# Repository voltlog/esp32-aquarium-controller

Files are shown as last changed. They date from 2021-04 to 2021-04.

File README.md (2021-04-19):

# ESP32 Aquarium/Terarrium Controller

This project started when a friend of mine which has a snake terrarium asked for my help to build a system that is capable of regulating temperature and humidity so the snake can live in optimum conditions. I’m not necessarily a snake lover, I would rather stay away from these kinds of creatures but that doesn’t stop me from helping my friend.

The ESP32 module is the core of this board and it serves as a central processor taking in sensor data and deciding when to switch on/off the 4 relay controlled outputs to adjust the environment inside the aquarium/terrarium.

If you would like to order one of these boards ready assembled, check out my [Tindie store](https://www.tindie.com/products/voltlog/esp32-aquarium-terrarium-controller/).

More info about this project in [Voltlog #361](https://youtu.be/Hlmbx2yu9M0).

Known issues in revA:
- Power brick module footprint is wrong so it needs to be installed on the bottom side of the board. 
- There are no mounting holes.
- Fitting the board inside the intended enclosure required some adjustments on the round cutouts. This is something to consider if you want to use the same enclosure but if you plan to install this in a larger plastic enclosure, it shouldn't be a problem.

## Firmware
Firmware is built as a PlatformIO project on the Arduino platform using publicly available open-source libraries. The HTML page servered by the asyncronous web server needs to be loaded into the ESP32 SPIFFS memory using the standard upload procedure. The code is just a proof of concept and is provided AS IS without warranty of any kind.

## Safety Warning
This control board uses mains voltage so you need to know what you are doing, otherwise, there is a high risk of electrical shock and/or fire. This is a serious topic, if you are not sure what you are doing, ask for help from an electrician. Every connection should be double checked before applying mains power.

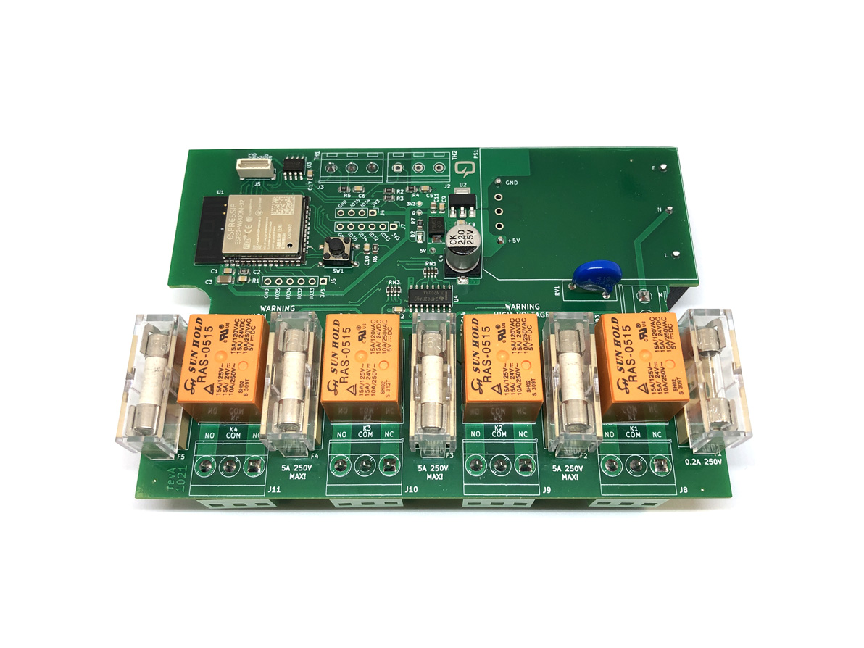
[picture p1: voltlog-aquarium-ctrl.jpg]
Image of the assembled PCB


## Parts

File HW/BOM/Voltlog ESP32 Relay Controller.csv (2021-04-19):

Qty | Reference(s) | Value | Footprint
9 | C1, C2, C5, C6, C8, C9, C10, C12, C17 | 0.1uF | Capacitor_SMD:C_0805_2012Metric
1 | C3 | 22uF | Capacitor_SMD:C_1206_3216Metric
1 | C4 | 220uF | Capacitor_SMD:CP_Elec_8x10.5
6 | C7, C11, C13, C14, C15, C16 | 10uF | Capacitor_SMD:C_0805_2012Metric
1 | D1 | SMBJ6.0A | Diode_SMD:D_SMB
1 | D2 | POWER | LED_SMD:LED_0805_2012Metric
4 | D3, D4, D5, D6 | CH1 | LED_SMD:LED_0805_2012Metric
1 | F1 | 250V 0.5A (slow) | Fuse:Fuseholder_Cylinder-5x20mm_Stelvio-Kontek_PTF78_Horizontal_Open
4 | F2, F3, F4, F5 | Fuse | Fuse:Fuseholder_Cylinder-5x20mm_Stelvio-Kontek_PTF78_Horizontal_Open
1 | J1 | AC_IN | TerminalBlock_RND:TerminalBlock_RND_205-00287_1x02_P5.08mm_Horizontal
1 | J2 | TH2 | TerminalBlock_RND:TerminalBlock_RND_205-00233_1x03_P5.08mm_Horizontal
1 | J3 | TH1 | TerminalBlock_RND:TerminalBlock_RND_205-00233_1x03_P5.08mm_Horizontal
1 | J4 | I2C | Connector_PinHeader_2.54mm:PinHeader_1x04_P2.54mm_Vertical
1 | J5 | VoltLink_target | Voltlog:VoltLink
1 | J6 | ADC | Connector_PinHeader_2.54mm:PinHeader_1x06_P2.54mm_Vertical
1 | J7 | GPIO | Connector_PinHeader_2.54mm:PinHeader_1x06_P2.54mm_Vertical
4 | J8, J9, J10, J11 |  | TerminalBlock_Phoenix:TerminalBlock_Phoenix_MKDS-3-3-5.08_1x03_P5.08mm_Horizontal
4 | K1, K2, K3, K4 | FINDER-36.11 | Relay_THT:Relay_SPDT_Finder_36.11
1 | PS1 | TAS5-5-W | Voltlog:TDPOWER-TAS5
2 | R1, R6 | 10K | Resistor_SMD:R_0805_2012Metric
4 | R2, R3, R4, R5 | 4K7 | Resistor_SMD:R_0805_2012Metric
1 | R7 | 1K | Resistor_SMD:R_0805_2012Metric
1 | RN1 | 270R | Resistor_SMD:R_Array_Convex_4x0603
1 | RN3 | 2K | Resistor_SMD:R_Array_Convex_4x0603
1 | RV1 | 275V | Varistor:RV_Disc_D12mm_W5mm_P7.5mm
1 | SW1 | USER | Button_Switch_SMD:SW_SPST_PTS645
1 | U1 | ESP32-WROOM-32D | RF_Module:ESP32-WROOM-32
1 | U2 | NCP1117-3.3_SOT223 | Package_TO_SOT_SMD:SOT-223-3_TabPin2
1 | U3 | FM24C64C | Package_SO:SOIC-8_3.9x4.9mm_P1.27mm
1 | U4 | ULN2003AD | Package_SO:SO-16_3.9x9.9mm_P1.27mm

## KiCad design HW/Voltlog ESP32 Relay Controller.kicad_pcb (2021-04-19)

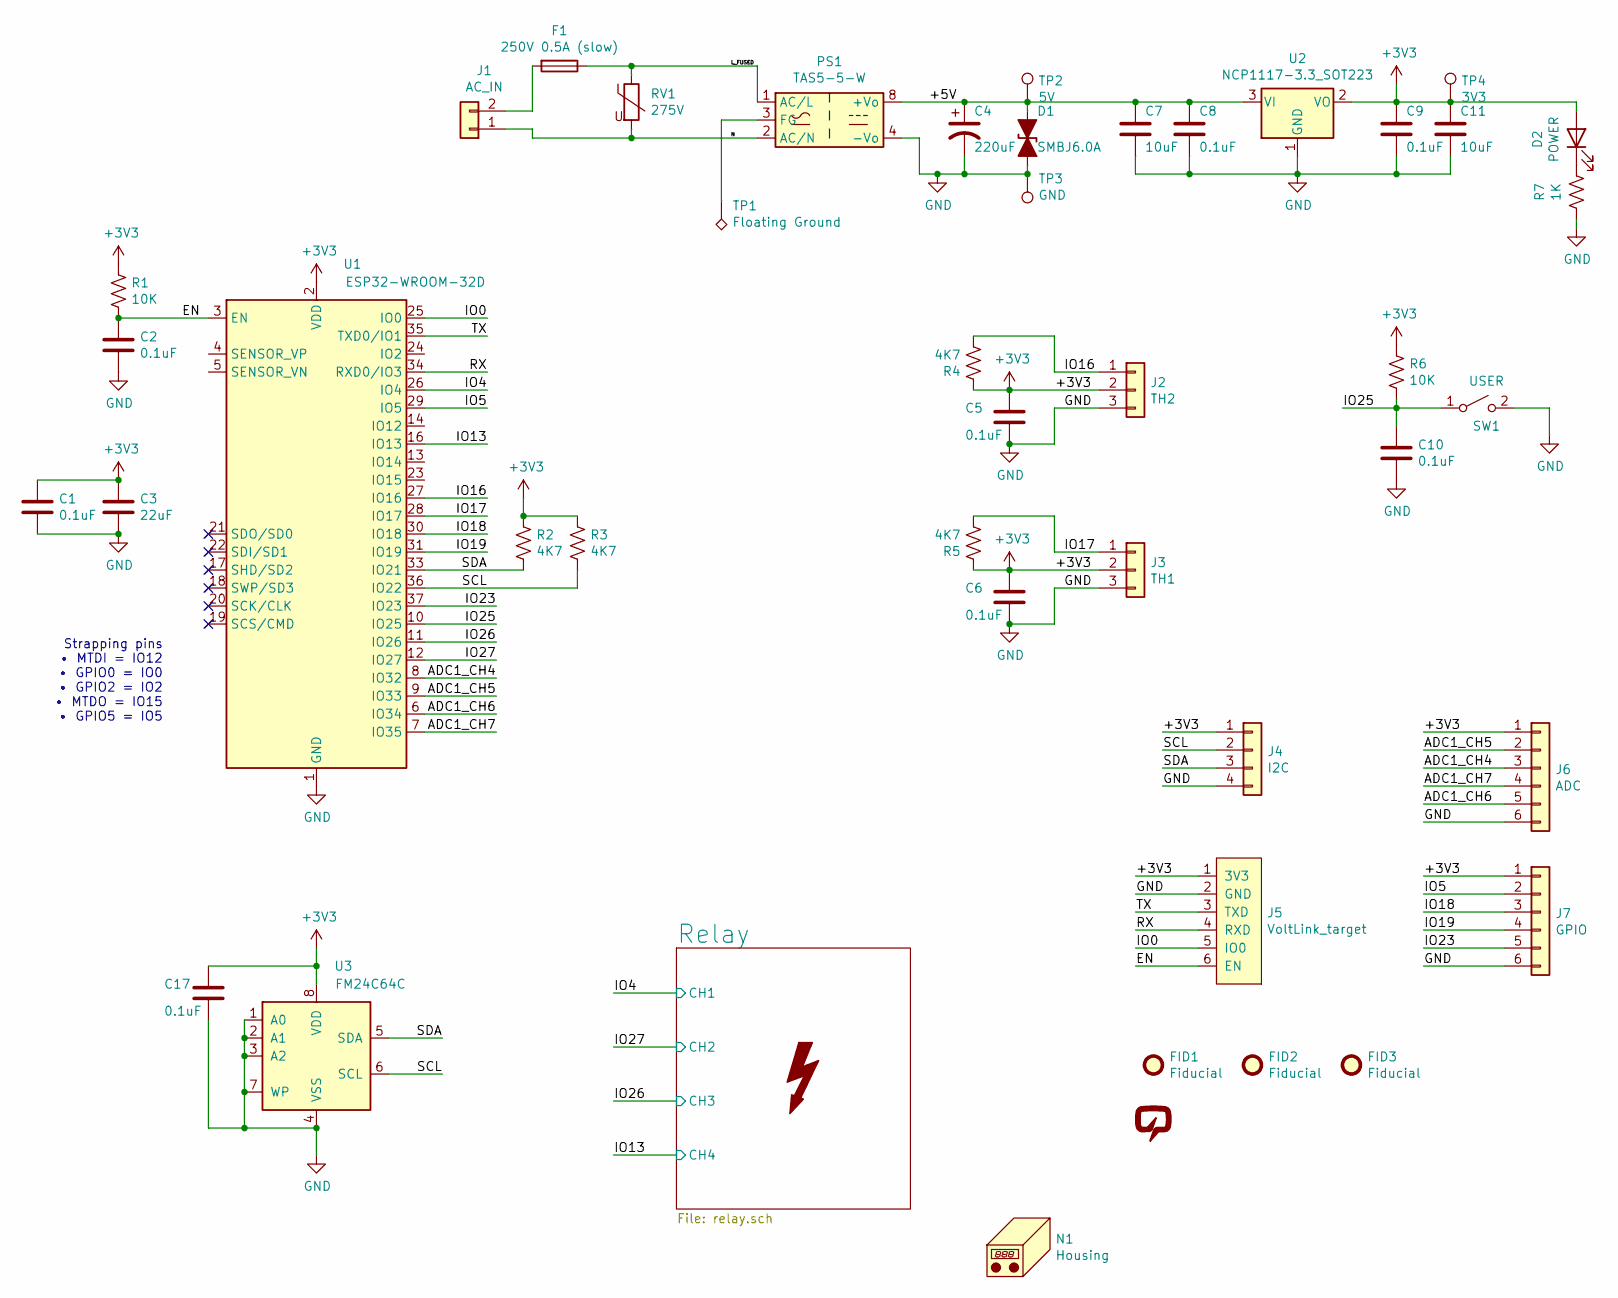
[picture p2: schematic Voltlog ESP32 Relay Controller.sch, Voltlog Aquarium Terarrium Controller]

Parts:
C1, C2, C5, C6, C8, C9, C10, C17: 0.1uF; C_0805_2012Metric
C3: 22uF; C_1206_3216Metric
C4: 220uF; CP_Elec_8x10.5; Voltage 25V
C7, C11: 10uF; C_0805_2012Metric
D1: SMBJ6.0A; D_SMB
D2: POWER; LED_0805_2012Metric
F1: 250V 0.5A (slow); Fuseholder_Cylinder-5x20mm_Stelvio-Kontek_PTF78_Horizontal_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
FID1, FID2, FID3: Fiducial; Fiducial_0.5mm_Mask1mm
J1: AC_IN; TerminalBlock_RND_205-00287_1x02_P5.08mm_Horizontal
J2: TH2; TerminalBlock_RND_205-00233_1x03_P5.08mm_Horizontal
J3: TH1; TerminalBlock_RND_205-00233_1x03_P5.08mm_Horizontal
J4: I2C; PinHeader_1x04_P2.54mm_Vertical
J5: VoltLink_target; VoltLink
J6: ADC; PinHeader_1x06_P2.54mm_Vertical
J7: GPIO; PinHeader_1x06_P2.54mm_Vertical
N1: Housing; Bernic_BE4969842011
PS1: TAS5-5-W; TDPOWER-TAS5
R1, R6: 10K; R_0805_2012Metric
R2, R3, R4, R5: 4K7; R_0805_2012Metric
R7: 1K; R_0805_2012Metric
RV1: 275V; RV_Disc_D12mm_W5mm_P7.5mm
SW1: USER; SW_SPST_PTS645
TP1: Floating Ground; SolderWirePad_1x01_SMD_5x10mm
TP2: 5V; TestPoint_Pad_D1.0mm
TP3: GND; TestPoint_Pad_D1.0mm
TP4: 3V3; TestPoint_Pad_D1.0mm
U1: ESP32-WROOM-32D; ESP32-WROOM-32
U2: NCP1117-3.3_SOT223; SOT-223-3_TabPin2
U3: FM24C64C; SOIC-8_3.9x4.9mm_P1.27mm
V1: VOLTLOG_LOGO; voltlog_mask_5mm

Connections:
+3V3: C1.1, C3.1, C5.1, C6.1, C9.1, C11.1, C17.1, D2.2 (A), J2.2, J3.2, J4.1, J5.1 (3V3), J6.1, J7.1, R1.1, R2.1, R3.1, R4.1, R5.1, R6.1, TP4.1, U1.2 (VDD), U2.2 (VO), U3.8 (VDD)
+5V: C4.1, C7.1, C8.1, D1.1 (A1), PS1.8 (+Vo), TP2.1, U2.3 (VI); also elsewhere on the board
/ADC1_CH4: J6.3, U1.8 (IO32)
/ADC1_CH5: J6.2, U1.9 (IO33)
/ADC1_CH6: J6.5, U1.6 (IO34)
/ADC1_CH7: J6.4, U1.7 (IO35)
/EN: C2.1, J5.6 (EN), R1.2, U1.3 (EN)
/IO0: J5.5 (IO0), U1.25 (IO0)
/IO2: U1.24 (IO2)
/IO4: U1.26 (IO4); also elsewhere on the board
/IO5: J7.2, U1.29 (IO5)
/IO13: U1.16 (IO13); also elsewhere on the board
/IO16: J2.1, R4.2, U1.27 (IO16)
/IO17: J3.1, R5.2, U1.28 (IO17)
/IO18: J7.3, U1.30 (IO18)
/IO19: J7.4, U1.31 (IO19)
/IO23: J7.5, U1.37 (IO23)
/IO25: C10.1, R6.2, SW1.1 (A), U1.10 (IO25)
/IO26: U1.11 (IO26); also elsewhere on the board
/IO27: U1.12 (IO27); also elsewhere on the board
/L_FUSED: F1.1, PS1.1 (AC/L), RV1.1
/N: J1.1, PS1.2 (AC/N), RV1.2
/RX: J5.4 (RXD), U1.34 (RXD0/IO3)
/SCL: J4.2, R3.2, U1.36 (IO22), U3.6 (SCL)
/SDA: J4.3, R2.2, U1.33 (IO21), U3.5 (SDA)
/TX: J5.3 (TXD), U1.35 (TXD0/IO1)
GND: C1.2, C2.2, C3.2, C4.2, C5.2, C6.2, C7.2, C8.2, C9.2, C10.2, C11.2, C17.2, D1.2 (A2), J2.3, J3.3, J4.4, J5.2 (GND), J6.6, J7.6, PS1.4 (-Vo), R7.2, SW1.2 (B), TP3.1, U1.1 (GND), U1.15 (GND), U1.38 (GND), U1.39 (GND), U2.1 (GND), U3.1 (A0), U3.2 (A1), U3.3 (A2), U3.4 (VSS), U3.7 (WP); also elsewhere on the board
unnamed: D2.1 (K), R7.1
unnamed: F1.2, J1.2
unnamed: PS1.3 (FG), TP1.1

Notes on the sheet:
Strapping pins • MTDI = IO12 • GPIO0 = IO0 • GPIO2 = IO2 • MTDO = IO15 • GPIO5 = IO5

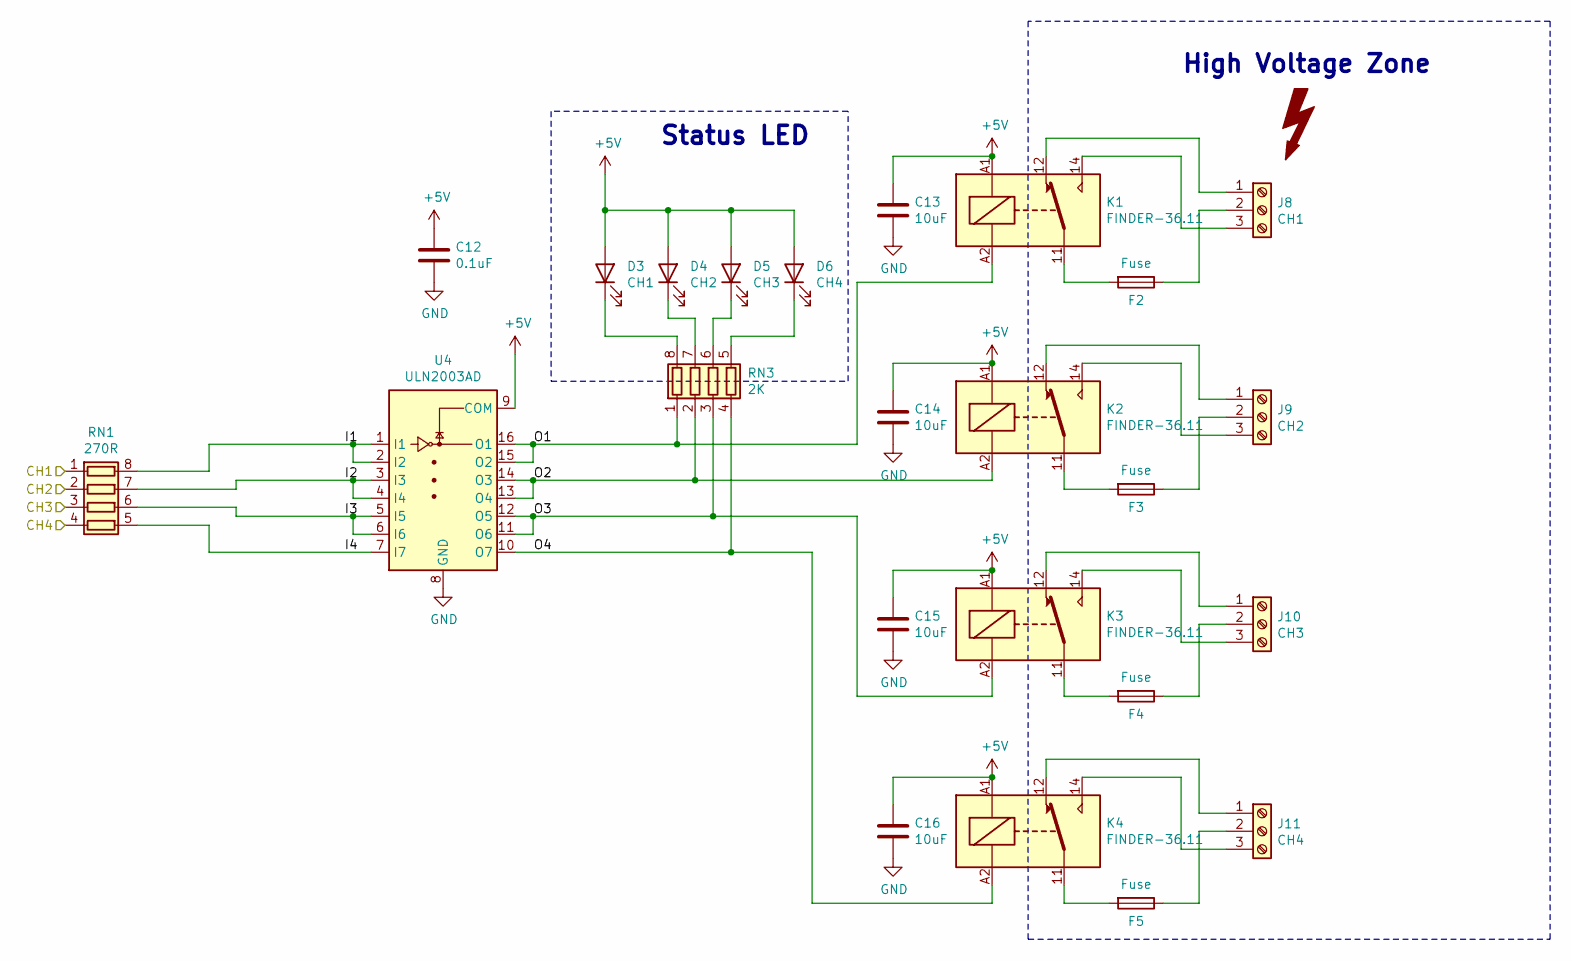
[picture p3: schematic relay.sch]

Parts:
C12: 0.1uF; C_0805_2012Metric
C13, C14, C15, C16: 10uF; C_0805_2012Metric
D3: CH1; LED_0805_2012Metric
D4: CH2; LED_0805_2012Metric
D5: CH3; LED_0805_2012Metric
D6: CH4; LED_0805_2012Metric
F2, F3, F4, F5: Fuse; Fuseholder_Cylinder-5x20mm_Stelvio-Kontek_PTF78_Horizontal_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
J8: CH1; TerminalBlock_Phoenix_MKDS-3-3-5.08_1x03_P5.08mm_Horizontal
J9: CH2; TerminalBlock_Phoenix_MKDS-3-3-5.08_1x03_P5.08mm_Horizontal
J10: CH3; TerminalBlock_Phoenix_MKDS-3-3-5.08_1x03_P5.08mm_Horizontal
J11: CH4; TerminalBlock_Phoenix_MKDS-3-3-5.08_1x03_P5.08mm_Horizontal
K1, K2, K3, K4: FINDER-36.11; Relay_SPDT_Finder_36.11
RN1: 270R; R_Array_Convex_4x0603
RN3: 2K; R_Array_Convex_4x0603
U4: ULN2003AD; SO-16_3.9x9.9mm_P1.27mm

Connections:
+5V: C12.1, C13.2, C14.2, C15.2, C16.2, D3.2 (A), D4.2 (A), D5.2 (A), D6.2 (A), K1.A1, K2.A1, K3.A1, K4.A1, U4.9 (COM); also elsewhere on the board
/IO4: RN1.1 (R1.1); also elsewhere on the board
/IO13: RN1.4 (R4.1); also elsewhere on the board
/IO26: RN1.3 (R3.1); also elsewhere on the board
/IO27: RN1.2 (R2.1); also elsewhere on the board
/Relay/I1: RN1.8 (R1.2), U4.1 (I1), U4.2 (I2)
/Relay/I2: RN1.7 (R2.2), U4.3 (I3), U4.4 (I4)
/Relay/I3: RN1.6 (R3.2), U4.5 (I5), U4.6 (I6)
/Relay/I4: RN1.5 (R4.2), U4.7 (I7)
/Relay/O1: K1.A2, RN3.1 (R1.1), U4.15 (O2), U4.16 (O1)
/Relay/O2: K2.A2, RN3.2 (R2.1), U4.13 (O4), U4.14 (O3)
/Relay/O3: K3.A2, RN3.3 (R3.1), U4.11 (O6), U4.12 (O5)
/Relay/O4: K4.A2, RN3.4 (R4.1), U4.10 (O7)
GND: C12.2, C13.1, C14.1, C15.1, C16.1, U4.8 (GND); also elsewhere on the board
unnamed: D3.1 (K), RN3.8 (R1.2)
unnamed: D4.1 (K), RN3.7 (R2.2)
unnamed: D5.1 (K), RN3.6 (R3.2)
unnamed: D6.1 (K), RN3.5 (R4.2)
unnamed: F2.1, J8.2
unnamed: F2.2, K1.11
unnamed: F3.1, J9.2
unnamed: F3.2, K2.11
unnamed: F4.1, J10.2
unnamed: F4.2, K3.11
unnamed: F5.1, J11.2
unnamed: F5.2, K4.11
unnamed: J8.1, K1.12
unnamed: J8.3, K1.14
unnamed: J9.1, K2.12
unnamed: J9.3, K2.14
unnamed: J10.1, K3.12
unnamed: J10.3, K3.14
unnamed: J11.1, K4.12
unnamed: J11.3, K4.14

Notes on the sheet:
High Voltage Zone
Status LED

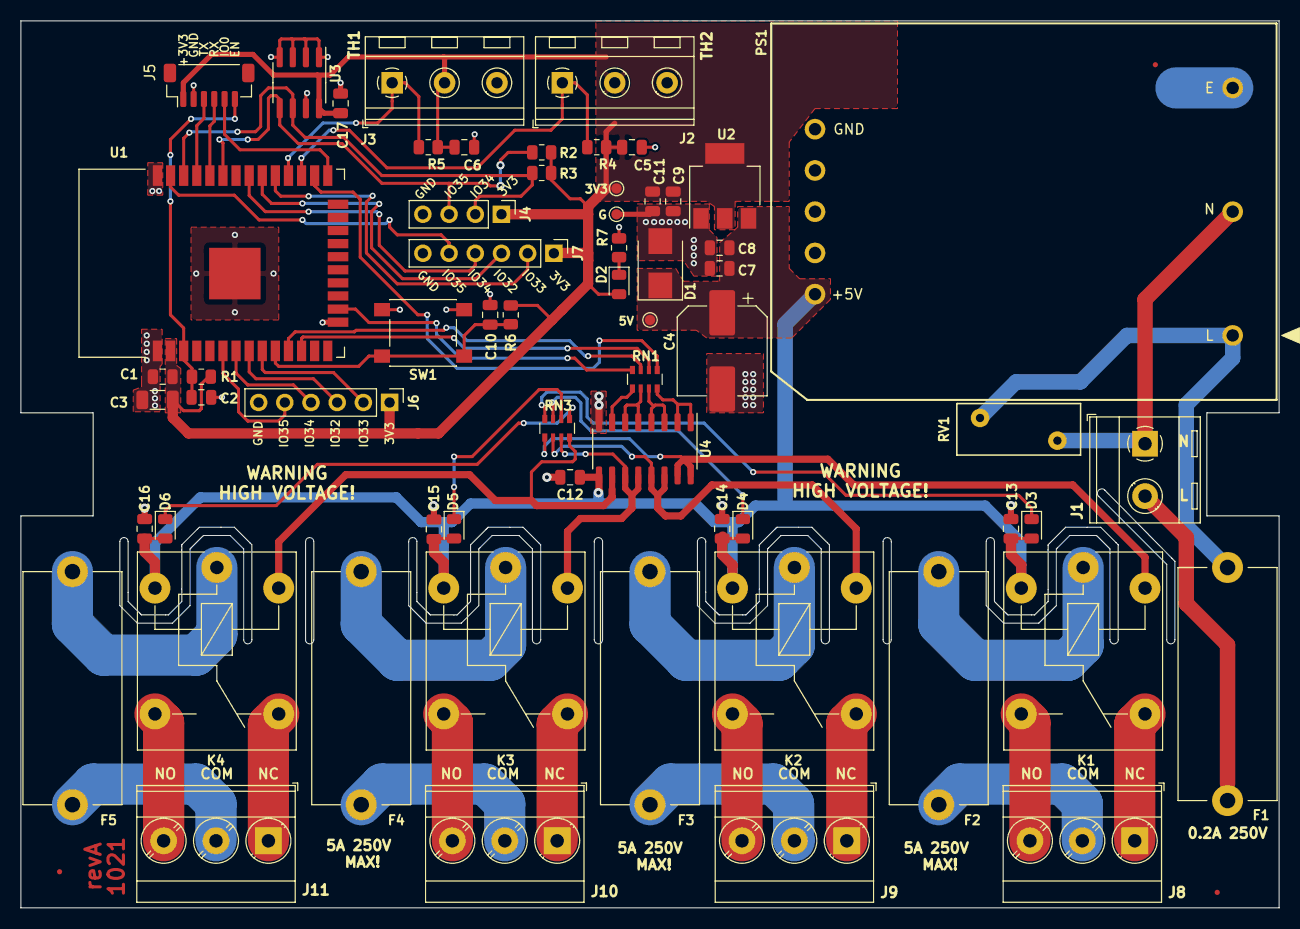
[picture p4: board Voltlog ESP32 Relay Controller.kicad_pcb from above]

Board: 2 copper layers, 122.0 x 86.0 mm, 68 parts (1 on the bottom side), 57 nets.

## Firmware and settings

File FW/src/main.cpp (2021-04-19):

/*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
For more details check out Voltlog #361

This is a work in progress, many of the functions below can be incomplete or may not work
*/
#include <Arduino.h>
#include <WiFi.h>
#include <time.h>
#include <Adafruit_Sensor.h>
#include <DHT.h>
#include <DHT_U.h>
#include <SPIFFS.h>
#include <ESPAsyncWebServer.h>

#define K1pin 4
#define K2pin 27
#define K3pin 26
#define K4pin 13
#define SWITCH 25
#define SENSOR1 17
#define SENSOR2 16
#define DHTTYPE    DHT11     // DHT 11 sensor
#define HEATER K1pin
#define HUMIDIFIER K2pin

const int TEMP1_SET_POINT = 23; // degrees C
int TEMP1 = 0;
const int TEMP1_HYSTERESIS = 1; // 1 degree C of hysteresis
const int HUM1_SET_POINT = 50; // percent
int HUM1 = 0;
const int HUM1_HYSTERESIS = 5; // 5% of hysteresis


String K1status = "OFF";
String K2status = "OFF";
String K3status = "OFF";
String K4status = "OFF";
String Temperature = "-";
String Humidity = "-";
String Mode = "manual";


const char* ssid       = "ssid";
const char* password   = "password";

const char* ntpServer = "pool.ntp.org";
const long  gmtOffset_sec = 7200; //GMT+2 in seconds
const int   daylightOffset_sec = 3600;  //daylight saving in sec
char date_buff[32];

sensor_t sensor1;
DHT_Unified dht(SENSOR1, DHTTYPE);
AsyncWebServer server(80);

void printLocalTime();
char * returnLocalTime();
int getDaylightSavings();
void printSensorDiagnostic();
void printSensorData();
void getSensorData();
String processor(const String& var);
void updateHumidifier();
void updateHeater();
void configWebServer();


void setup() {
  // Init UART interface
  Serial.begin(115200);

  // Init SPIFFS
  if(!SPIFFS.begin()){
  Serial.println("An Error has occurred while mounting SPIFFS");
  return;
  }

  // Init IO pins
  pinMode(K1pin, OUTPUT);
  pinMode(K2pin, OUTPUT);
  pinMode(K3pin, OUTPUT);
  pinMode(K4pin, OUTPUT);
  pinMode(SWITCH, INPUT);

  // Init & connect to WiFi
  Serial.printf("Connecting to %s ", ssid);
  WiFi.begin(ssid, password);
  while (WiFi.status() != WL_CONNECTED) {
      delay(500);
      Serial.print(".");
  }
  Serial.println(" CONNECTED");
  Serial.print("Got IP: ");  Serial.println(WiFi.localIP());

  //config webserver
  configWebServer();

  //config time
  Serial.println("Configuring NTP service and fetching current time.");
  configTime(gmtOffset_sec, 0, ntpServer);  //start with DST 0 to be able to config and get initial time
  printLocalTime();
  Serial.println("Adjusting for DST.");
  configTime(gmtOffset_sec, getDaylightSavings(), ntpServer);
  printLocalTime();

  //Initialize DHT sensor
  dht.begin();
  //printSensorDiagnostic();


  //Print stored config variables
  Serial.println("Retrieving stored settings from memory...");
  Serial.print  (F("TEMP1_SET_POINT: ")); Serial.println(TEMP1_SET_POINT);
  Serial.print  (F("TEMP1_HYSTERESIS: ")); Serial.println(TEMP1_HYSTERESIS);
  Serial.print  (F("HUM1_SET_POINT: ")); Serial.println(HUM1_SET_POINT);
  Serial.print  (F("HUM1_HYSTERESIS: ")); Serial.println(HUM1_HYSTERESIS);


  delay(1000);
  Serial.println("System ready.");
}

void loop() {
  
  //printLocalTime();
  getSensorData();
  printSensorData();
  updateHumidifier();
  updateHeater();

  delay(1000);

  //TODO Add safety checks for temp / hum values
  //TODO add watchdog that resets system in case of lockup


  // RUN THIS TO UPDATE TIME FRON NTP SERVER
  //  configTime(gmtOffset_sec, getDaylightSavings(), ntpServer);

}

String processor(const String& var){
  if (var == "TIME"){
    return returnLocalTime();
  }
  else if (var == "TEMP"){
    return Temperature;
  }
  else if (var == "HUMIDITY"){
    return Humidity;
  }
  else if (var == "OUTPUT1_STATUS"){
    return K1status;
  }
  else if (var == "OUTPUT2_STATUS"){
    return K2status;
  }
  else if (var == "OUTPUT3_STATUS"){
    return K3status;
  }
  else if (var == "OUTPUT4_STATUS"){
    return K4status;
  }
  return String();
}

void getSensorData()
{
    // Get temperature event and print its value.
  sensors_event_t event;
  dht.temperature().getEvent(&event);
  if (isnan(event.temperature)) {
   //Serial.println(F("Error reading temperature!"));
  }
  else {
    //Serial.print(F("Temperature: "));
    //Serial.print(event.temperature);
    //Serial.println(F("°C"));
    TEMP1 = event.temperature;
    Temperature = event.temperature;
  }
  // Get humidity event and print its value.
  dht.humidity().getEvent(&event);
  if (isnan(event.relative_humidity)) {
    //Serial.println(F("Error reading humidity!"));
  }
  else {
    //Serial.print(F("Humidity: "));
    //Serial.print(event.relative_humidity);
    //Serial.println(F("%"));
    HUM1 = event.relative_humidity;
    Humidity = event.relative_humidity;
  }
}

//config webserver
void configWebServer() {
  server.on("/", HTTP_GET, [](AsyncWebServerRequest *request){request->send(SPIFFS, "/index.html", String(), false, processor);});
  server.on("/bootstrap.min.css", HTTP_GET, [](AsyncWebServerRequest *request){request->send(SPIFFS, "/bootstrap.min.css", "text/css");});
  server.on("/output1_on", HTTP_GET, [](AsyncWebServerRequest *request){digitalWrite(K1pin, HIGH);K1status="ON";request->send(SPIFFS, "/index.html", String(), false, processor);});
  server.on("/output1_off", HTTP_GET, [](AsyncWebServerRequest *request){digitalWrite(K1pin, LOW);K1status="OFF";request->send(SPIFFS, "/index.html", String(), false, processor);});
  server.on("/output2_on", HTTP_GET, [](AsyncWebServerRequest *request){digitalWrite(K2pin, HIGH);K2status="ON";request->send(SPIFFS, "/index.html", String(), false, processor);});
  server.on("/output2_off", HTTP_GET, [](AsyncWebServerRequest *request){digitalWrite(K2pin, LOW);K2status="OFF";request->send(SPIFFS, "/index.html", String(), false, processor);});
  server.on("/output3_on", HTTP_GET, [](AsyncWebServerRequest *request){digitalWrite(K3pin, HIGH);K3status="ON";request->send(SPIFFS, "/index.html", String(), false, processor);});
  server.on("/output3_off", HTTP_GET, [](AsyncWebServerRequest *request){digitalWrite(K3pin, LOW);K3status="OFF";request->send(SPIFFS, "/index.html", String(), false, processor);});
  server.on("/output4_on", HTTP_GET, [](AsyncWebServerRequest *request){digitalWrite(K4pin, HIGH);K4status="ON";request->send(SPIFFS, "/index.html", String(), false, processor);});
  server.on("/output4_off", HTTP_GET, [](AsyncWebServerRequest *request){digitalWrite(K4pin, LOW);K4status="OFF";request->send(SPIFFS, "/index.html", String(), false, processor);});

  server.on("/temperature", HTTP_GET, [](AsyncWebServerRequest *request){request->send_P(200, "text/plain", Temperature.c_str());});
  server.on("/humidity", HTTP_GET, [](AsyncWebServerRequest *request){request->send_P(200, "text/plain", Humidity.c_str());});
  server.on("/time", HTTP_GET, [](AsyncWebServerRequest *request){request->send_P(200, "text/plain", returnLocalTime());});
  server.on("/auto", HTTP_GET, [](AsyncWebServerRequest *request){Mode="auto";request->send_P(200, "text/plain", Mode.c_str());});
  server.on("/manual", HTTP_GET, [](AsyncWebServerRequest *request){Mode="manual";request->send_P(200, "text/plain", Mode.c_str());});
  server.on("/get_mode", HTTP_GET, [](AsyncWebServerRequest *request){request->send_P(200, "application/json", Mode.c_str());});
  
  server.begin();
}

//Function that controls the heater output
void updateHeater() {                         
  static double lastTemp = 0;
  if (lastTemp != TEMP1) {
    digitalWrite(HEATER, TEMP1 <= TEMP1_SET_POINT - TEMP1_HYSTERESIS ? HIGH : LOW);
    lastTemp = TEMP1;
  }
}

void updateHumidifier() {                         
  static double lastHum = 0;
  if (lastHum != HUM1) {
    digitalWrite(HUMIDIFIER, HUM1 <= HUM1_SET_POINT - HUM1_HYSTERESIS ? HIGH : LOW);
    lastHum = HUM1;
  }
}

void printLocalTime()
{
  struct tm timeinfo;
  if(!getLocalTime(&timeinfo)){
    Serial.println("Failed to obtain time");
    return;
  }
  Serial.println(&timeinfo, "%A, %B %d %Y %H:%M:%S");
}

char * returnLocalTime()
{
  struct tm timeinfo;
  
  if(!getLocalTime(&timeinfo)){
    Serial.println("Failed to obtain time");
  } 
  strftime(date_buff, 32, "%A, %B %d %Y %H:%M:%S", &timeinfo);
  return date_buff;

}


int getDaylightSavings()
{
  struct tm timeinfo;
  int daylightOffset;
  
  if(!getLocalTime(&timeinfo)){
    Serial.println("Failed to obtain time");
  } 
  daylightOffset =  daylightOffset_sec * timeinfo.tm_isdst;
  return daylightOffset;
}

void printSensorDiagnostic()
{
  dht.temperature().getSensor(&sensor1);
  Serial.println(F("------------------------------------"));
  Serial.println(F("Temperature Sensor"));
  Serial.print  (F("Sensor Type: ")); Serial.println(sensor1.name);
  Serial.print  (F("Driver Ver:  ")); Serial.println(sensor1.version);
  Serial.print  (F("Unique ID:   ")); Serial.println(sensor1.sensor_id);
  Serial.print  (F("Max Value:   ")); Serial.print(sensor1.max_value); Serial.println(F("°C"));
  Serial.print  (F("Min Value:   ")); Serial.print(sensor1.min_value); Serial.println(F("°C"));
  Serial.print  (F("Resolution:  ")); Serial.print(sensor1.resolution); Serial.println(F("°C"));
  Serial.println(F("------------------------------------"));
  // Print humidity sensor details.
  dht.humidity().getSensor(&sensor1);
  Serial.println(F("Humidity Sensor"));
  Serial.print  (F("Sensor Type: ")); Serial.println(sensor1.name);
  Serial.print  (F("Driver Ver:  ")); Serial.println(sensor1.version);
  Serial.print  (F("Unique ID:   ")); Serial.println(sensor1.sensor_id);
  Serial.print  (F("Max Value:   ")); Serial.print(sensor1.max_value); Serial.println(F("%"));
  Serial.print  (F("Min Value:   ")); Serial.print(sensor1.min_value); Serial.println(F("%"));
  Serial.print  (F("Resolution:  ")); Serial.print(sensor1.resolution); Serial.println(F("%"));
  Serial.println(F("------------------------------------"));
}

void printSensorData()
{
  // Get temperature event and print its value.
  sensors_event_t event;
  dht.temperature().getEvent(&event);
  if (isnan(event.temperature)) {
    Serial.println(F("Error reading temperature!"));
  }
  else {
    Serial.print(F("Temperature: "));
    Serial.print(event.temperature);
    Serial.println(F("°C"));
  }
  // Get humidity event and print its value.
  dht.humidity().getEvent(&event);
  if (isnan(event.relative_humidity)) {
    Serial.println(F("Error reading humidity!"));
  }
  else {
    Serial.print(F("Humidity: "));
    Serial.print(event.relative_humidity);
    Serial.println(F("%"));
  }
}

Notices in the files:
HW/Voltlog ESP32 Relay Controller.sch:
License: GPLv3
